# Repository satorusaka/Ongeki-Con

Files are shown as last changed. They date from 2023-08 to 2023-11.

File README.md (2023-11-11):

# ONGEKI Controller Build

DIY Controller for Ongeki.

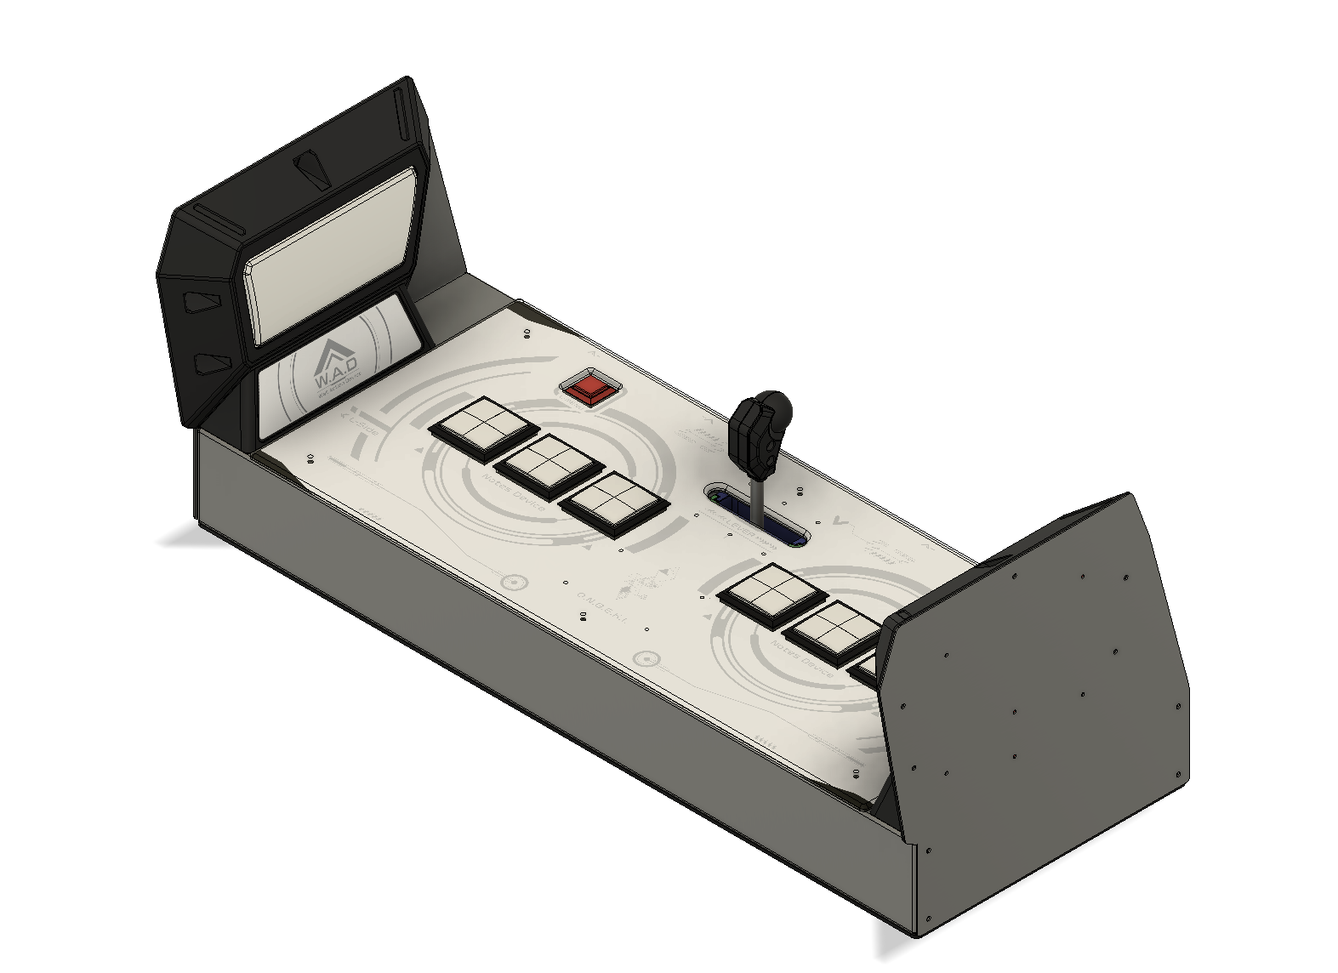
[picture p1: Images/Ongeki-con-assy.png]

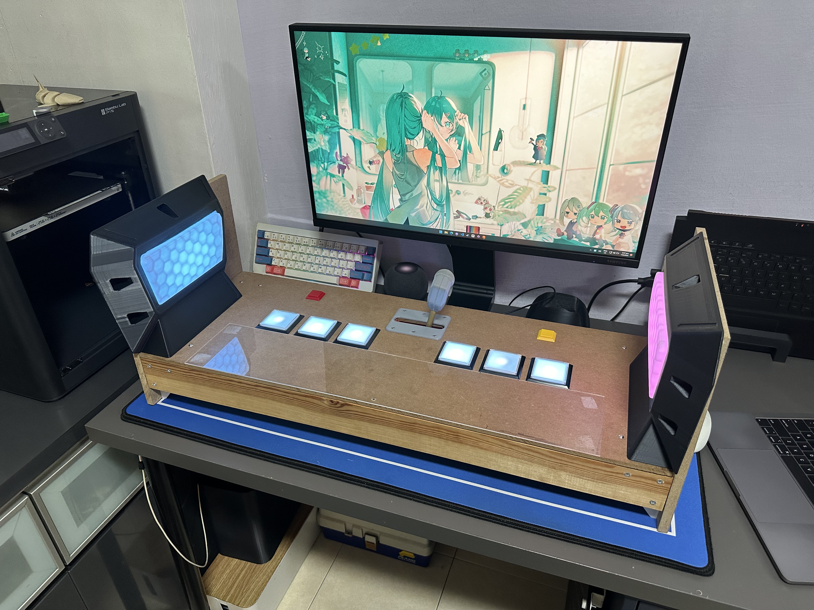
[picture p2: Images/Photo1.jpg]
Assembly photo

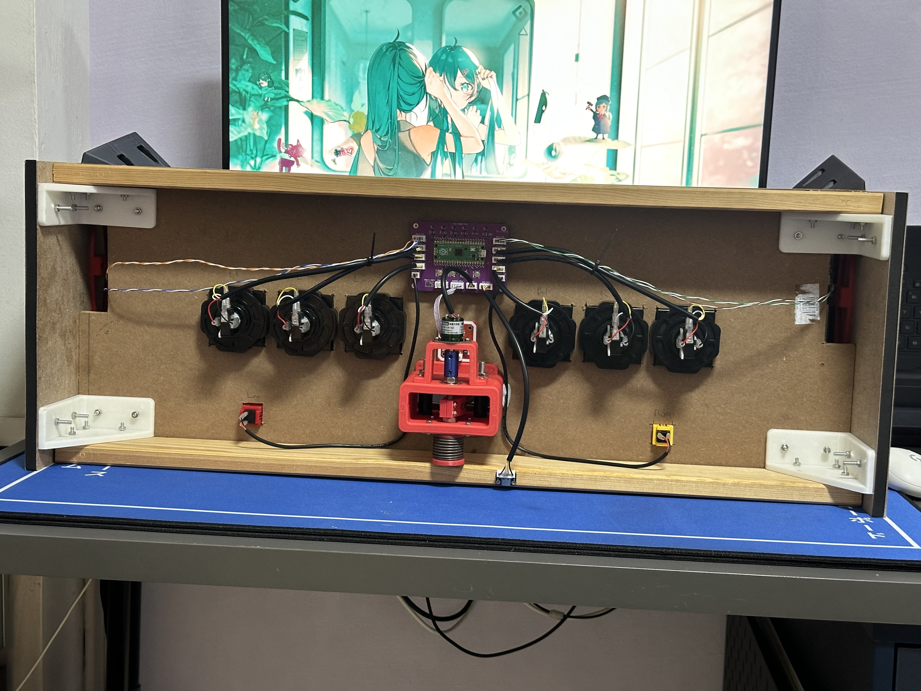
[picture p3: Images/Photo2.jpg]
Assembly photo


## TODO

- Add Main pcb files and documentation
- Complete case design

## Required parts

- 22AWG wire
- various XH connectors
- various Female Spade Crimp Terminals for buttons
- USB-C breakout board

## Raspberry Pi Pico breakout Board (FILES NOT READY)

Documentation in [main-PCB](main-PCB/README.md).
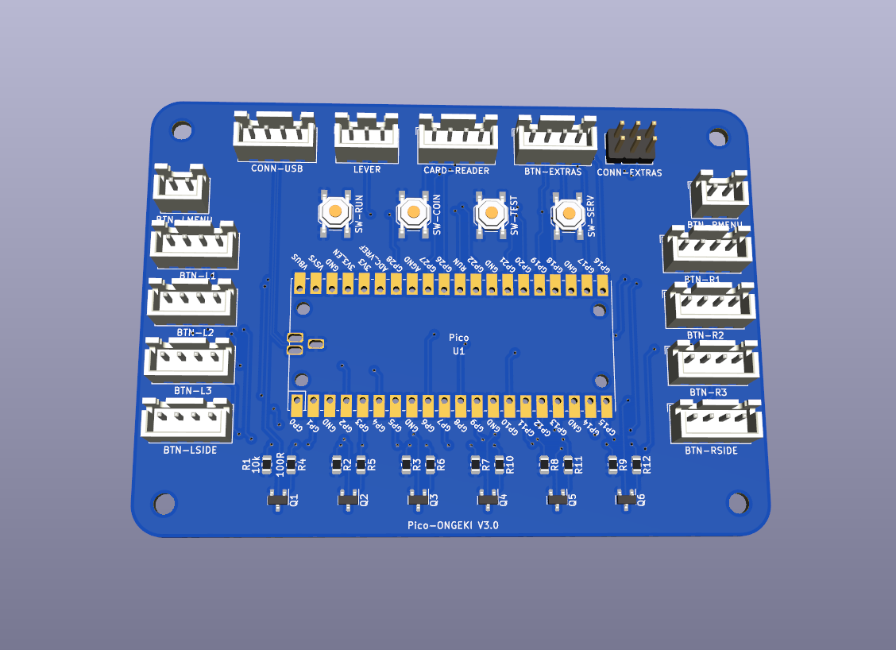
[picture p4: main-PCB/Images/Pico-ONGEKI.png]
Pico-ONFGKI v3.0


## Wall Attack Device (WAD) sub-assembly

Documentation in [WAD assembly](WAD%20assembly/README.md).
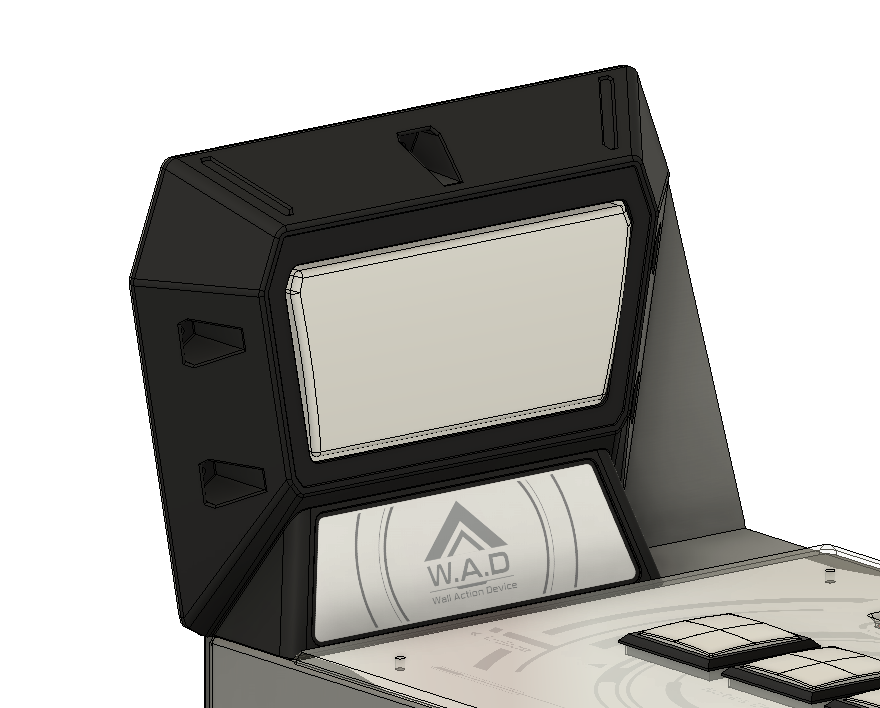
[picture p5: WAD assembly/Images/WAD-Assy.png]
WAD Photo


## Swing Mechanism sub-assembly

Documentation in [Swing assembly](Swing%20assembly/README.md).
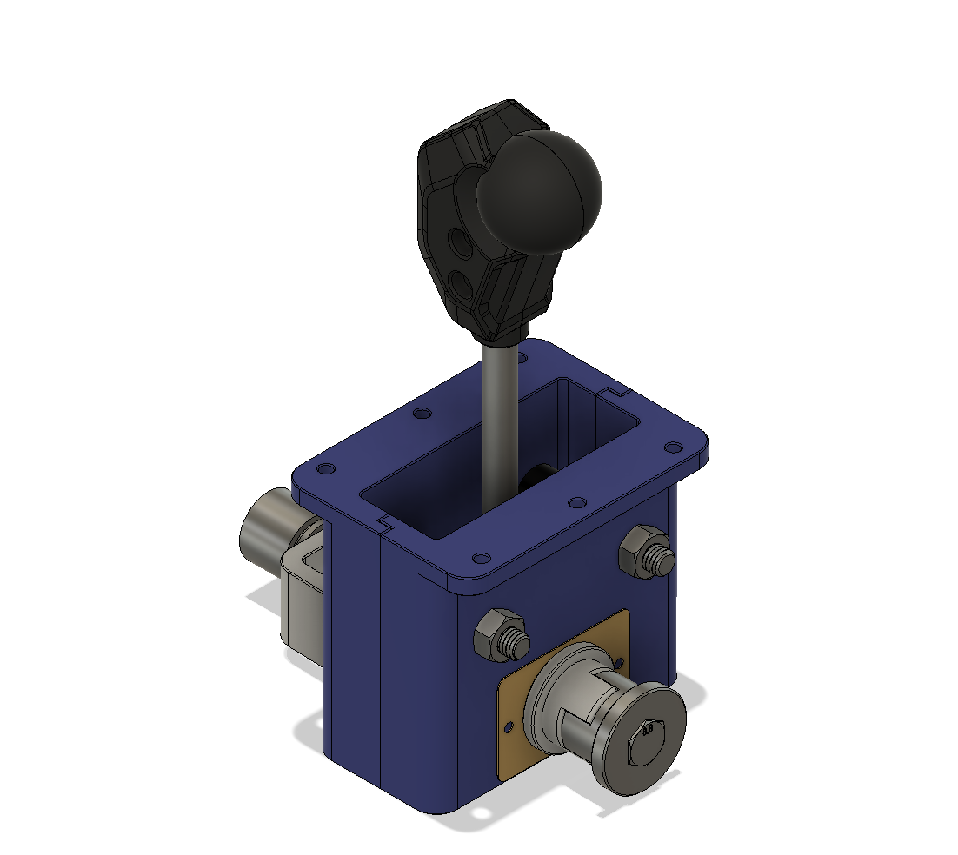
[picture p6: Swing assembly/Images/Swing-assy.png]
Swing Mechanism


## Buttons

[Rhythm-cons.wiki: Buttons Guide](https://rhythm-cons.wiki/w/Buttons)

### Main buttons (x6)

- Sanwa OBSA-60UK 60mm Square button
- using [Mintyleds](https://shop.mon.im/product/mintyleds)
- Links
  - [Sanwa Official Store](https://www.rakuten.co.jp/sanwadenshi/)
  - [IST 60UK](https://www.us.istmall.co.kr/Product/Detail/view/pid/67/cid/)
  - AliExpress: 60mm square arcade button

### Menu buttons (x2) (1 Yellow, 1 Red)

- OBSF-24KK YELLOW & RED 24mm square button
- Links
  - [Sanwa Official Store](https://www.rakuten.co.jp/sanwadenshi/)
  - AliExpress: 24mm square arcade button

### Extra buttons (Test,Service,coin) (x3)

- Sanwa OBSF-24 24mm round buttons
- Links
  - [Sanwa Official Store](https://www.rakuten.co.jp/sanwadenshi/)
  - [IST 24mm](https://www.us.istmall.co.kr/Product/Detail/view/pid/25/cid/)
  - AliExpress: 24mm round arcade button

## Case

- mdf / sheet-metal
- Dimensions: 783x295x90mm (WxDxH)

### WAD Walls

- mdf / sheet-metal
- T-Nut to attach side wall to Main body
- slide down from top to attach

### Control Panel Acrylic

- Dimensions: 669x295mm (WxD)
- 5mm thick
- 3mm chamfers
- 5mm rounded corner

#### Panel Graphics printing options

- [silkscreen printing](https://www.acrylic.com.sg/silkscreen-printing/)
- UV printing
- Poster Paper

# License

This work is licensed under [CC BY-NC-SA 4.0](http://creativecommons.org/licenses/by-nc-sa/4.0/?ref=chooser-v1)

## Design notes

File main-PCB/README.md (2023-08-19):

# Pico-ONGEKI v3.0 (Needs Documenting)

Pico-ONFGKI v3.0

- 13 Buttons connections
  - 6 Main Buttons
    - Button + MintyLED
  - 2 WAD Buttons
    - Button + WS2812b (panel or strips)
  - 2 Menu Buttons
  - Test Button
  - Service Button
  - Coin Button
- Lever analog connector
- USB breakout board connector
- card reader connector

## configuration needed

Needs the correct io file.

Configure COM ports to port 1 & 3. for LED and Card Reader.

update stools conf

```ini
[aime]
enable=0
aimePath=DEVICE\aime.txt

[io4]
enable=0

[io3]
enable=0
```

## Firmware

Thanks \_LittleC\_! [satorusaka/lkick-io4](https://github.com/satorusaka/lkick-io4)

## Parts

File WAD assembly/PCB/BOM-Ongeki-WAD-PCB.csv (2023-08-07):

Comment | Designator | Footprint | LCSC
WS2812B | D1,D2,D3,D4,D5,D6,D7,D8 | LED_WS2812B_PLCC4_5.0x5.0mm_P3.2mm | C2761795
0.1uF | C1,C2,C3,C4,C5,C6,C7,C8 | C_0603_1608Metric | C30926
Conn_01x04 | J2 | JST_XH_S4B-XH-A_1x04_P2.50mm_Horizontal
Conn_01x03 | J1 | JST_XH_S3B-XH-A_1x03_P2.50mm_Horizontal

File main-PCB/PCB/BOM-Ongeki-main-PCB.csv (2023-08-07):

Comment | Designator | Footprint | LCSC
BTN-R1 | J4 | JST_XH_B4B-XH-A_1x04_P2.50mm_Vertical
BTN-R3 | J6 | JST_XH_B4B-XH-A_1x04_P2.50mm_Vertical
Pico | U1 | RPi_Pico_SMD_TH
CARD-READER | J14 | JST_XH_B4B-XH-A_1x04_P2.50mm_Vertical
BTN-L2 | J2 | JST_XH_B4B-XH-A_1x04_P2.50mm_Vertical
BTN-L3 | J3 | JST_XH_B4B-XH-A_1x04_P2.50mm_Vertical
BTN-LMENU | J9 | JST_XH_B2B-XH-A_1x02_P2.50mm_Vertical
BTN-LSIDE | J7 | JST_XH_B4B-XH-A_1x04_P2.50mm_Vertical
BTN-RSIDE | J8 | JST_XH_B4B-XH-A_1x04_P2.50mm_Vertical
BTN-RMENU | J10 | JST_XH_B2B-XH-A_1x02_P2.50mm_Vertical
BTN-L1 | J1 | JST_XH_B4B-XH-A_1x04_P2.50mm_Vertical
LEVER | J15 | JST_XH_B3B-XH-A_1x03_P2.50mm_Vertical
BTN-R2 | J5 | JST_XH_B4B-XH-A_1x04_P2.50mm_Vertical
BTN-EXTRAS | J18 | JST_XH_B4B-XH-A_1x04_P2.50mm_Vertical
CONN-EXTRAS | J17 | PinHeader_2x03_P2.54mm_Vertical
SW-RUN | SW1 | SW_SPST_TL3342
CONN-USB | J16 | JST_XH_B4B-XH-A_1x04_P2.50mm_Vertical
10k | R2 | R_0805_2012Metric
100R | R4 | R_0805_2012Metric
SW-SERV | SW2 | SW_SPST_TL3342
BSS138 | Q6 | SOT-23
100R | R6 | R_0805_2012Metric
10k | R3 | R_0805_2012Metric
10k | R9 | R_0805_2012Metric
BSS138 | Q2 | SOT-23
BSS138 | Q1 | SOT-23
10k | R8 | R_0805_2012Metric
100R | R10 | R_0805_2012Metric
10k | R1 | R_0805_2012Metric
10k | R7 | R_0805_2012Metric
SW-TEST | SW3 | SW_SPST_TL3342
BSS138 | Q5 | SOT-23
100R | R5 | R_0805_2012Metric
BSS138 | Q3 | SOT-23
BSS138 | Q4 | SOT-23
SW-COIN | SW4 | SW_SPST_TL3342
100R | R11 | R_0805_2012Metric
100R | R12 | R_0805_2012Metric

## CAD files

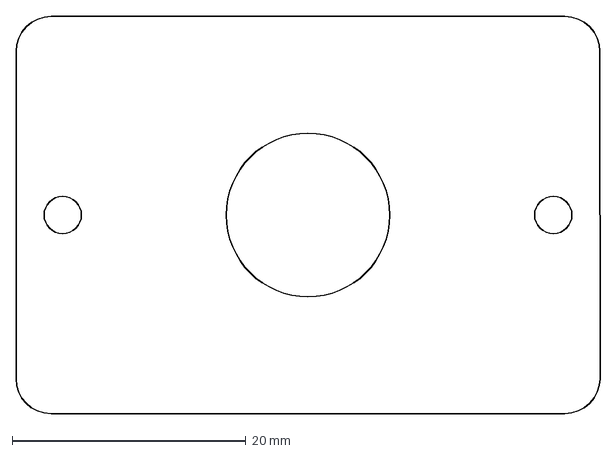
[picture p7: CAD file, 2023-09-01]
Swing assembly/DXF/Friction Plate.dxf
50.0 x 34.0 mm

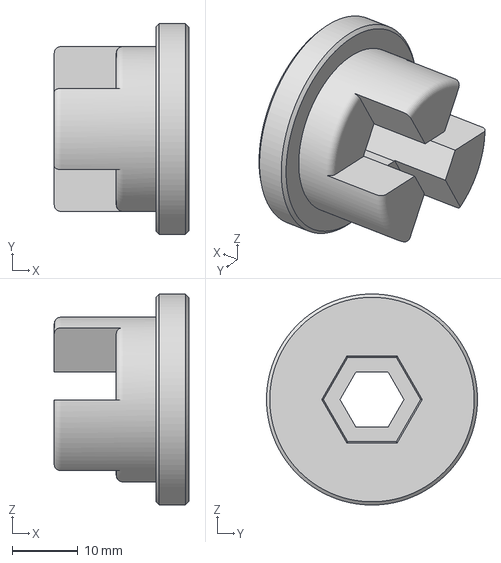
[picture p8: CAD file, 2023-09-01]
Swing assembly/STLs/Spring Holder B.3mf
20.4 x 32.0 x 32.0 mm

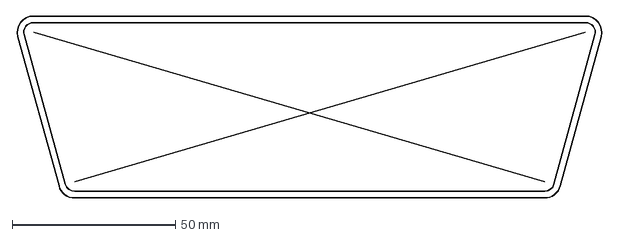
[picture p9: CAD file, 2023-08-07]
WAD assembly/Decal/WAD Decal Size.dxf
179.7 x 55.8 mm

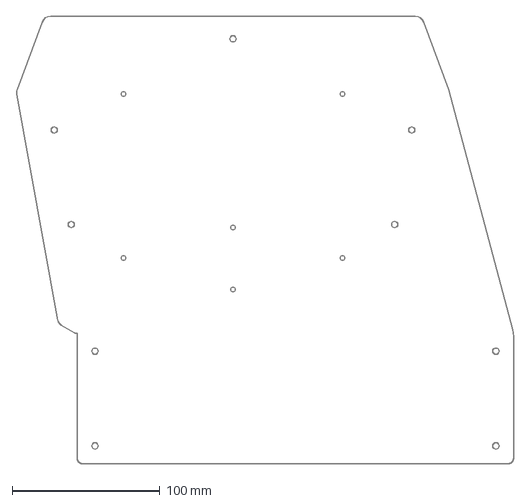
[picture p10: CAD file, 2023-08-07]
WAD assembly/DXFs/Side-Panel.dxf
336.1 x 302.4 mm

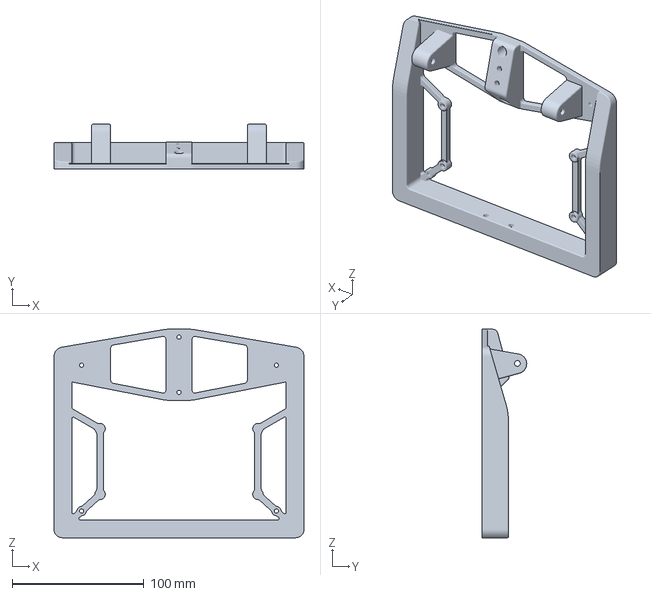
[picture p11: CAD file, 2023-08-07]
WAD assembly/STLs/WAD - Button Frame.3mf
190.0 x 33.9 x 158.5 mm

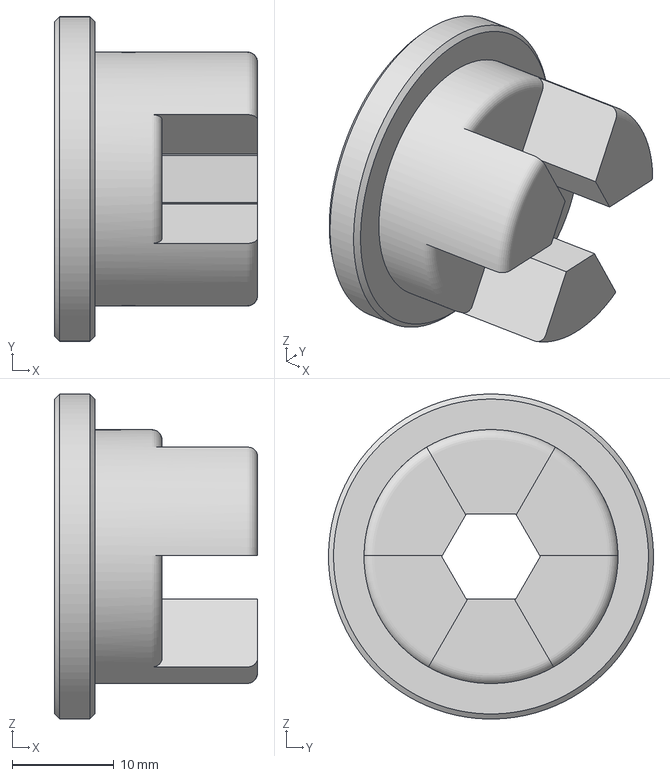
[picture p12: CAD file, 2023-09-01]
Swing assembly/STLs/Spring Holder A.3mf
20.0 x 32.0 x 32.0 mm

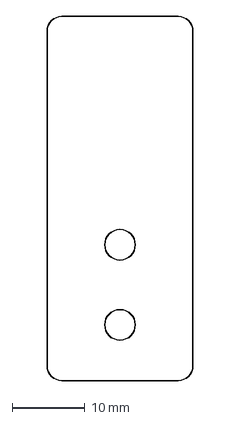
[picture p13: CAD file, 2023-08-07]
WAD assembly/DXFs/Flat Spring.dxf
20.0 x 50.0 mm

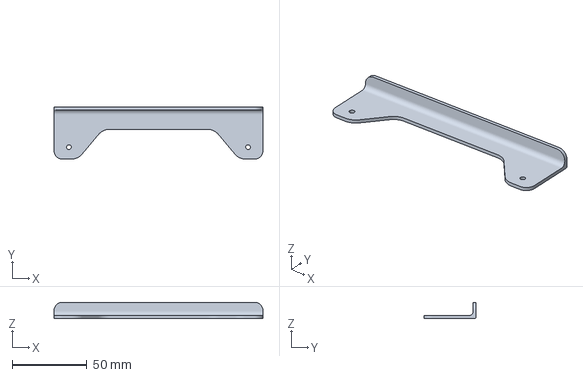
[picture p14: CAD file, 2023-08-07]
WAD assembly/STLs/WAD - Button Limiter.3mf
140.0 x 35.0 x 11.0 mm

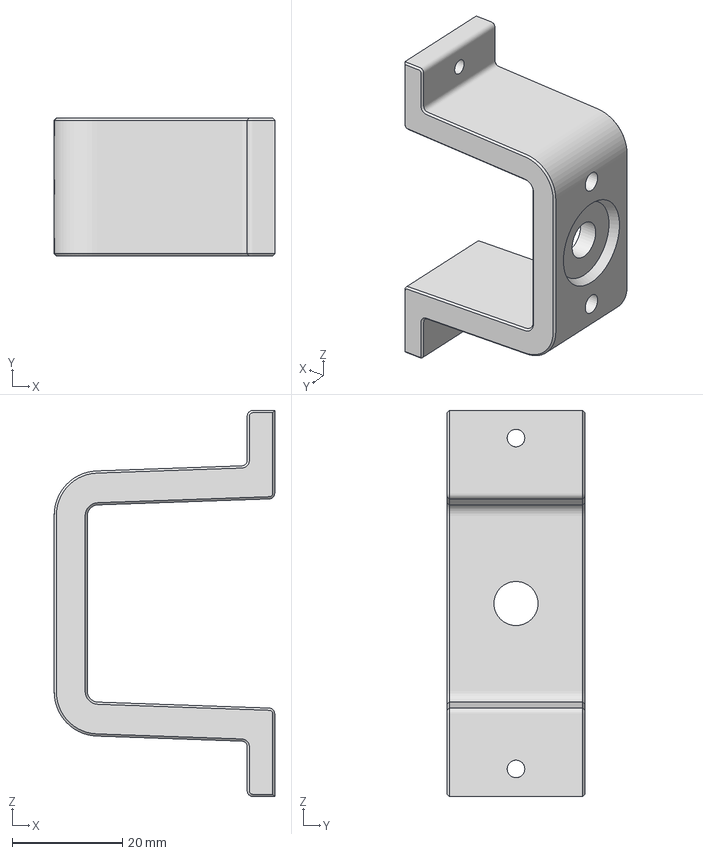
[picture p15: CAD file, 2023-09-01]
Swing assembly/STLs/Sensor Holder.3mf
40.0 x 25.0 x 70.0 mm

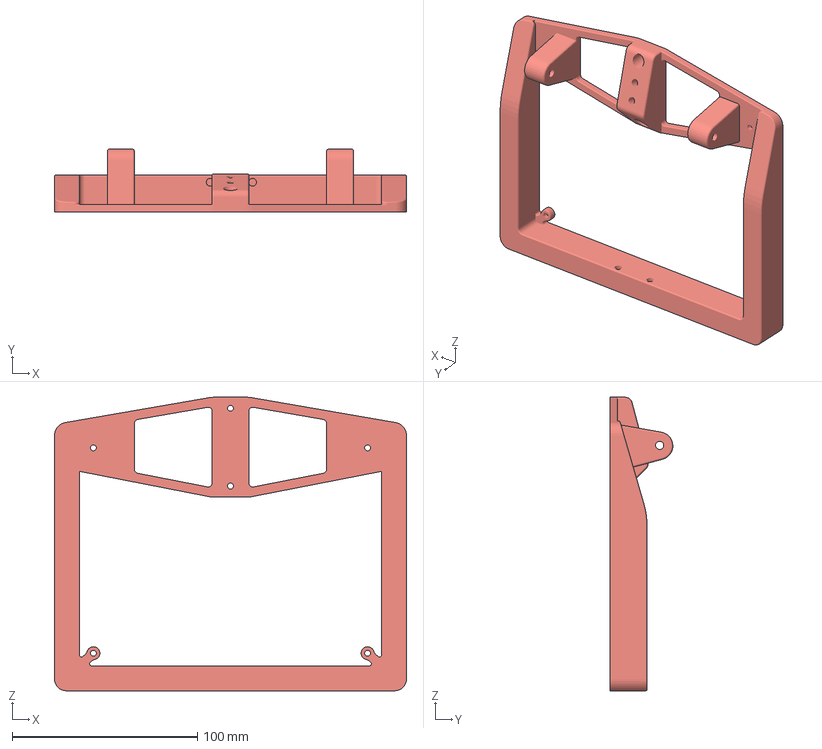
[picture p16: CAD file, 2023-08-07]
WAD assembly/STLs/WAD - Button Frame (No PCB).3mf
190.0 x 33.9 x 158.5 mm

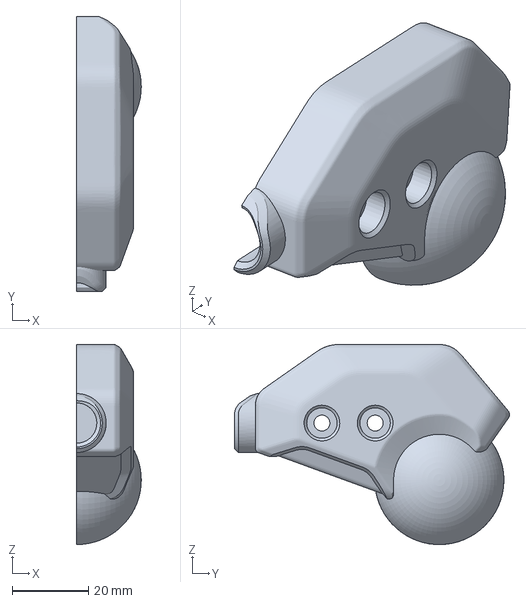
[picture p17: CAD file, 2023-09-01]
Swing assembly/STLs/Knob_R.3mf
17.0 x 72.3 x 52.7 mm

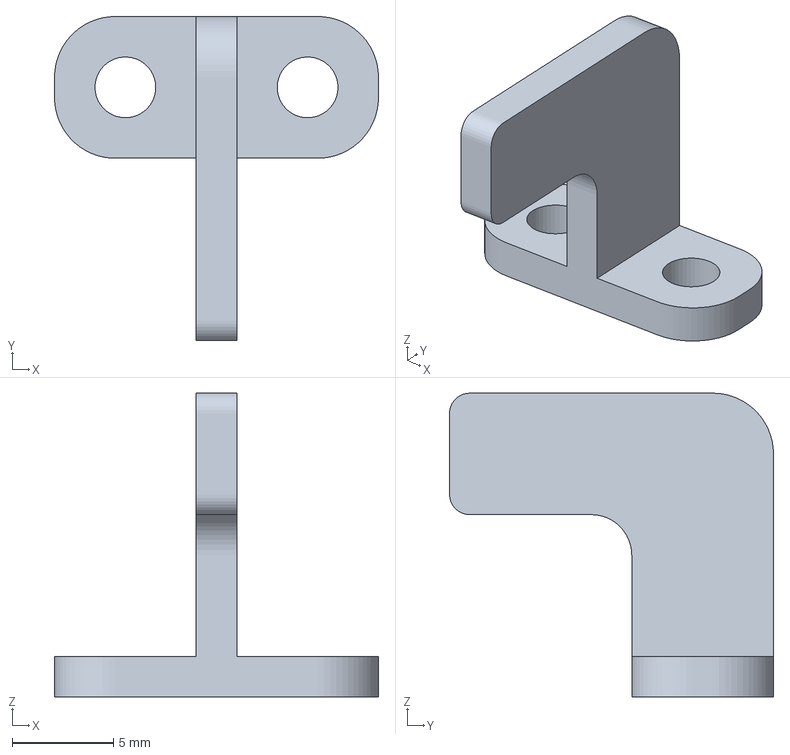
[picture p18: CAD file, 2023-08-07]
WAD assembly/STLs/WAD - Sensor Trigger.3mf
16.0 x 16.0 x 15.0 mm

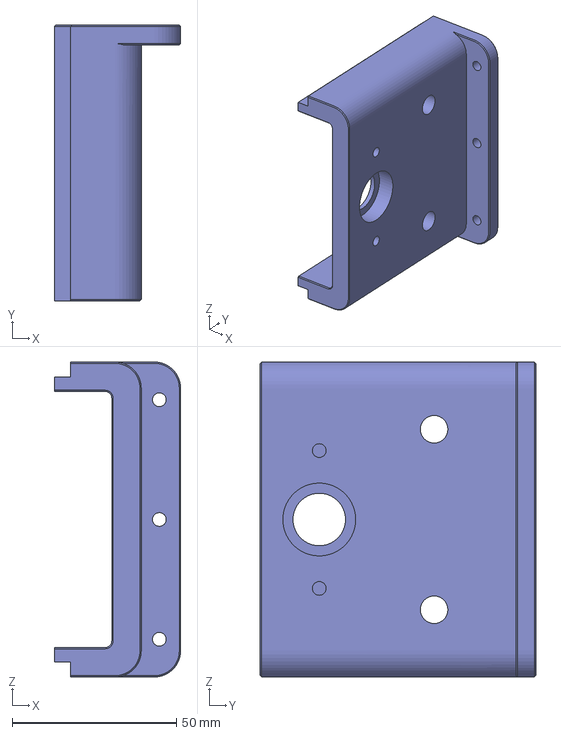
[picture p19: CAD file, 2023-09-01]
Swing assembly/STLs/Mount A.3mf
38.5 x 84.0 x 96.0 mm

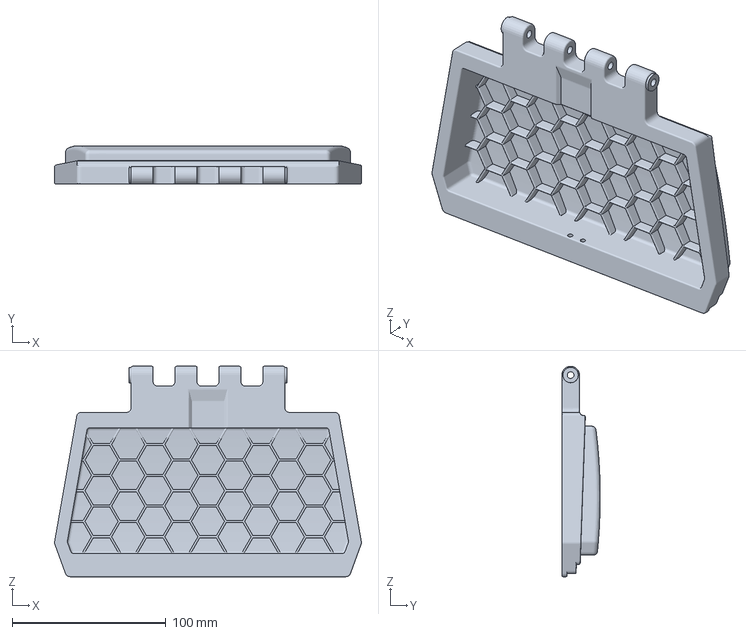
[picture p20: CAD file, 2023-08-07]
WAD assembly/STLs/WAD - Button Face.3mf
199.8 x 25.0 x 137.0 mm

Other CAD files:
Swing assembly/STLs/Mount B.3mf
WAD assembly/STLs/WAD - Cover.3mf
Swing assembly/STLs/Knob_L.3mf
Swing assembly/STLs/T-Coupler.3mf

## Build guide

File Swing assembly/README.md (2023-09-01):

# Swing Mechanism sub-assembly

I've designed this to be accurate to the original design and function.

There is a STEP file provided for this assembly, you can use it as a guide or modify it to your needs.

assy
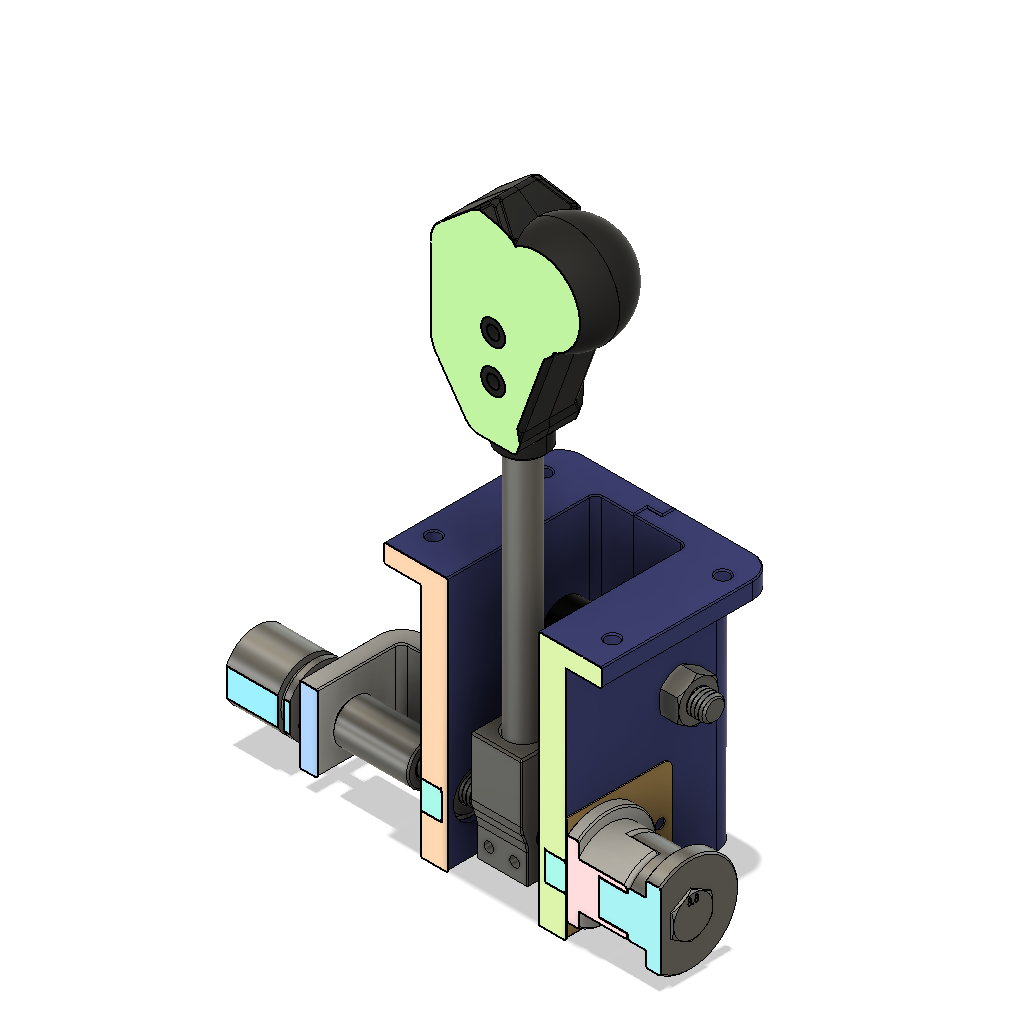
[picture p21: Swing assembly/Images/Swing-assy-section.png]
assy


[Photos below](#gallery)

## Required Parts

Additional custom parts and printed parts below.

| Part | Qty | Links |
| --- | --- | --- |
| Rubber Tube (8mm ID, 15mm OD, 23mm Length) | 2 | [8x14mm \(Cheaper\)](https://www.aliexpress.com/item/1005001683018083.html) or [8x15mm](https://www.aliexpress.com/item/1005001474127393.html) |
| Compression Spring (Wire Dia. : 2mm, Len. : 80mm, OD: 30mm) | 1 | [AliExpress](https://www.aliexpress.com/item/4000436939383.html) |
| Angle sensor 0-3.3V output | 1 | [AliExpress](https://www.aliexpress.com/item/32422949989.html) |
| 6x8 Shaft Coupler (D:14, L:25) | 1 | [AliExpress](https://www.aliexpress.com/item/1005001891597730.html) |
| 608 bearing | 2 | |
| M8x90 Hex Bolt. **pivot rod.** | 1 | |
| M8x60 Hex Bolt. **Stopper Rods.** | 2 | |
| M8 nuts (use threadlocker on pivot rod) | 5 | |
| M3x6 Bolt **angle sensor** | 2 | |
| M3 Countersunk Bolts(x6). (Len: 6mm + thickness of casing.) | 6 | |
| M3x10 Bolts **Friction plate** | 2 | |
| M3x16 Bolts **T-Coupler clamp** | 2 | |
| M3x6 Bolts **T-Coupler Handle rod** | 2 | |
| M3 Treaded Inserts | 12  | |
| M3 nuts | 2 | |
| Grease | 1 | |

## Printed Parts

| Parts | Qty | Notes |
| --- | --- | --- |
| Knob | 1 | |
| Mounts A & B | 1 | |
| sensor holder | 1 | |
| spring holder A & B | 1 | Recommended to print in PETG |
| T-coupler | 1 | Recommended to print in PETG |

## Custom Parts

### Handle Rod

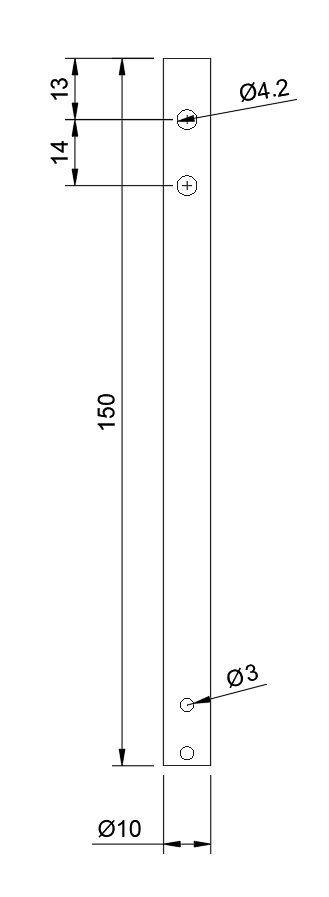
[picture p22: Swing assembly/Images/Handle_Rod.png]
Handle Rod Dimensions


- 10mm Dia., 150mm Len.
- brass/steel

### Friction Plate

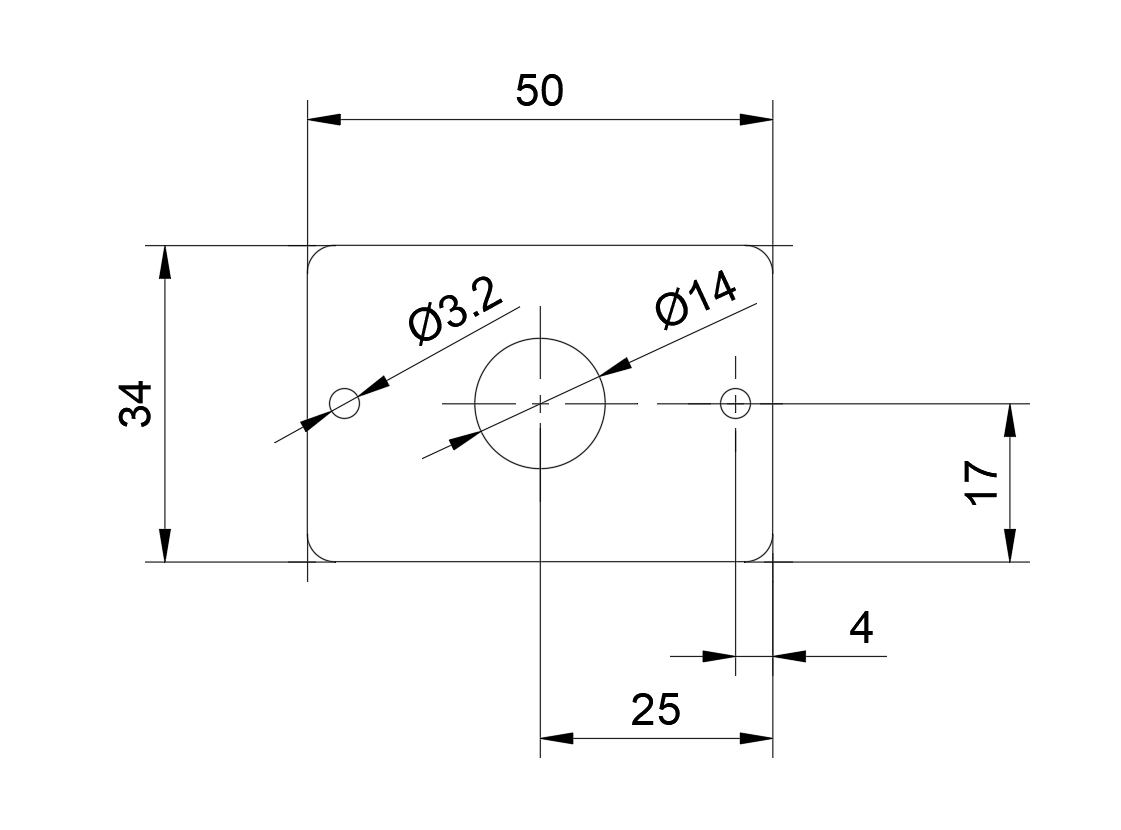
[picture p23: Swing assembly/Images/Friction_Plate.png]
Friction Plate Dimensions


- Dimensions: 34x50mm
- thickness: 0.64mm
- Sheet brass/steel
- apply grease on contacting surface.

## Gallery

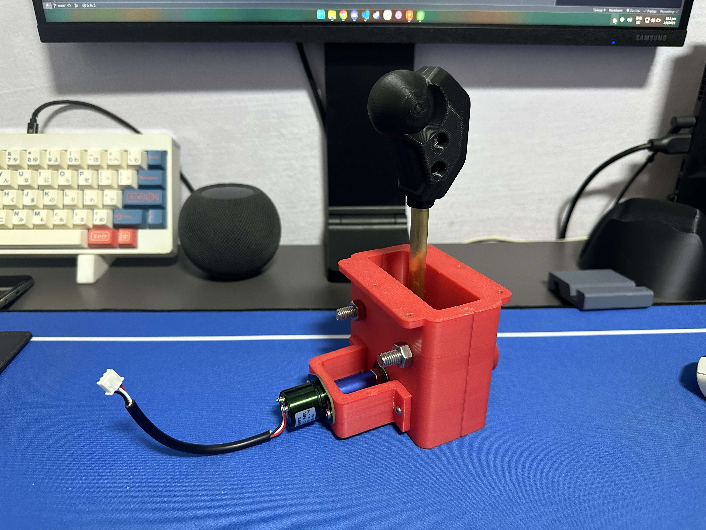
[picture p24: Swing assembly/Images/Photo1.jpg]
SwingAssy Photo

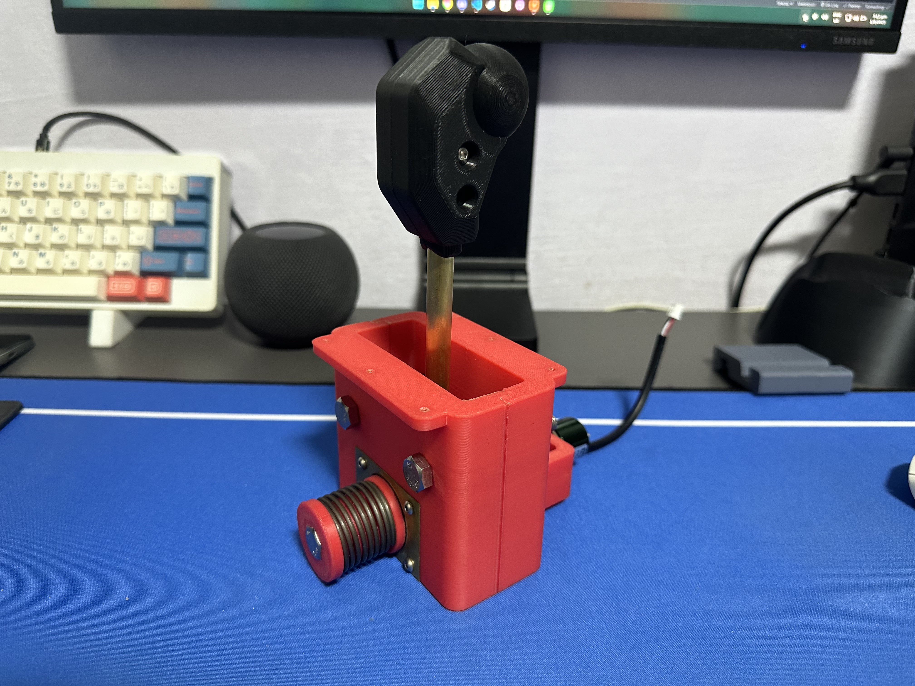
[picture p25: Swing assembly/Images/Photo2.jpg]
SwingAssy Photo

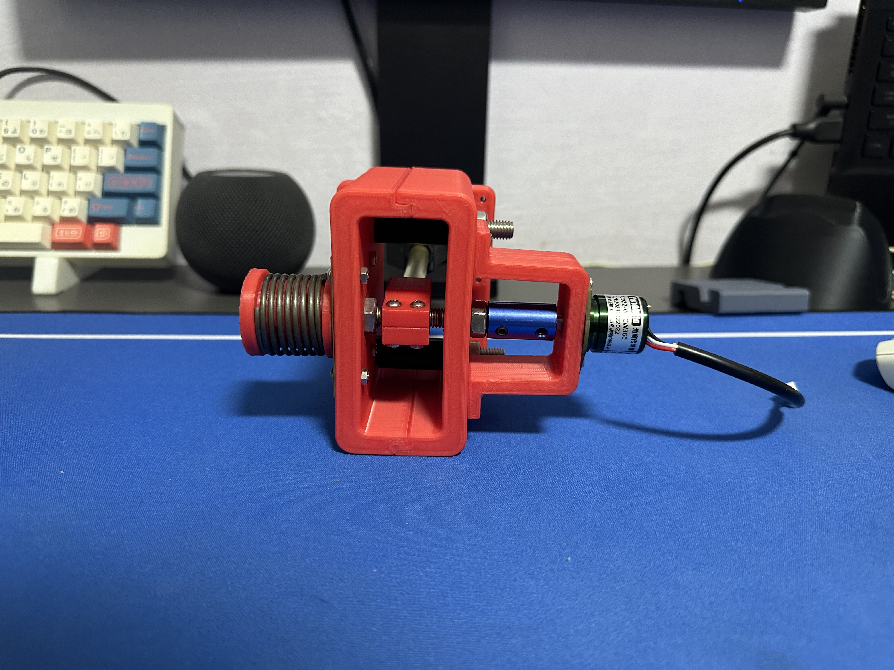
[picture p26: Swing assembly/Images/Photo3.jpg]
SwingAssy Photo


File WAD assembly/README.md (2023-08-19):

# Wall Attack Device (WAD) sub-assembly

I've designed this WAD to be accurate to the original design and function, using photo sensor for trigger, and flat spring for return mechanism.

There is a STEP file provided for this assembly, you can use it as a guide or modify it to your needs.

WAD Photo

[Photos below](#gallery)

## Required Parts

parts needed for the PCB are listed under the [PCB Section](#custom-wad-pcb). Additional custom parts and printed parts below.

| Part | Qty | Links |
| --- | --- | --- |
| LG-JT01 photo interrupter | 2 | [AliExpress](https://www.aliexpress.com/item/33015487463.html) |
| JST H3P-SHF-AA\* | 1 | [LCSC](https://www.lcsc.com/product-detail/_JST-Sales-America-_C495211.html) |
| JST SHF-001T-0.8BS\* | 3 | [LCSC](https://www.lcsc.com/product-detail/_JST-Sales-America-_C141769.html) |
| EVA foam tape, single sided, 10mm width, 1mm thick | 1 roll | [AliExpress](https://www.aliexpress.com/item/1005001829983926.html) |
| m3 threaded inserts | (x9 with pcb) or (x5 no pcb) | |
| m3x4 bolts | 4 (x2 for flat spring) (x2 for sensor trigger) | |
| m3x6 bolts | 6 (x4 for PCB) (x2 for Button Limiter) | |
| m3 bolts (button frame to side panel)\*\* | 6 | |
| m4 bolts (WAD cover to side panel)\*\* | 5 | |
| m3 and m4 nuts | | |

\* for connecting LG-JT01, alternatively you can use dupont connectors.

\*\* bolt length depends on panel thickness

## Printed Parts

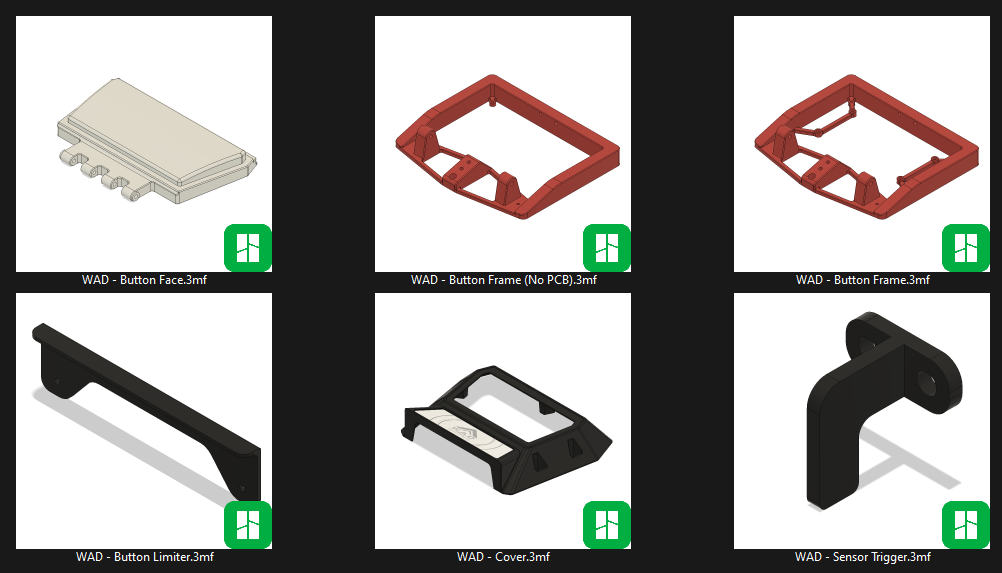
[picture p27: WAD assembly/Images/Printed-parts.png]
Printed Parts


Print 2 each, 1 per side. I recommend printing the button face vertically for a nicer looking surface.

| Parts | Qty | Notes |
| --- | --- | --- |
| Button Face | 2 | |
| Sensor Trigger | 2 | |
| Button Limiter | 2 | |
| WAD Cover | 2 | |
| Button Frame | 2 | Use (No PCB) if you are use LED strips instead of Custom WAD PCB |

## Custom Parts

### Flat Spring

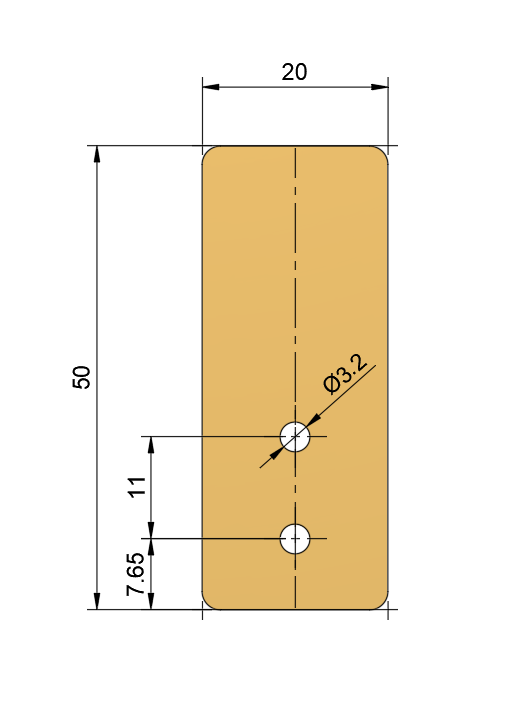
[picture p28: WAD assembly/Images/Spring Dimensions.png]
Flat Spring Dimensions


- Dimensions: 20x50mm
- thickness: 0.64mm
- Sheet brass/steel
- apply grease on contacting surface.

### Pivot Shaft

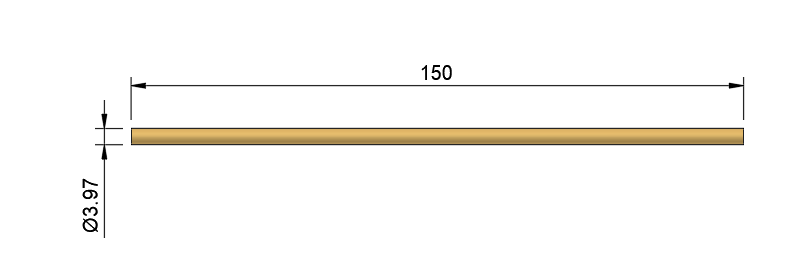
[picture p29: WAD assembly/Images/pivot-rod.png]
Pivot Dimensions


- 3.97mm dia., 150mm length
  Optionally, you can tap rod ends with M4 threads and use m4 nuts and washers on both ends to secure. personally I just use friction fit

### Custom WAD PCB

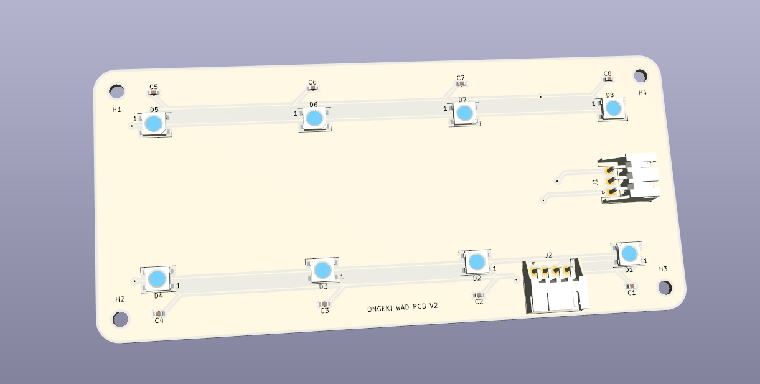
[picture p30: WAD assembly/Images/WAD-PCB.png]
WAD PCB


LED Panel with cable passthrough for Photosensor. Alternatively, you can use WS2812b LED Strips in place of the PCB.

#### BOM

| Part | qty |
| --- | --- |
| WS2812B | 8 |
| 0.1uF 0603 Capacitor | 8 |
| JST S4B-XH-A-1 | 1 |
| JST S3B-XH-A-1 | 1 |
| JST XHP-4 | 1 |
| JST XHP-3 | 1 |
| JST XH contacts | 7 |

### Sticker Decal
dimensions to be added. 
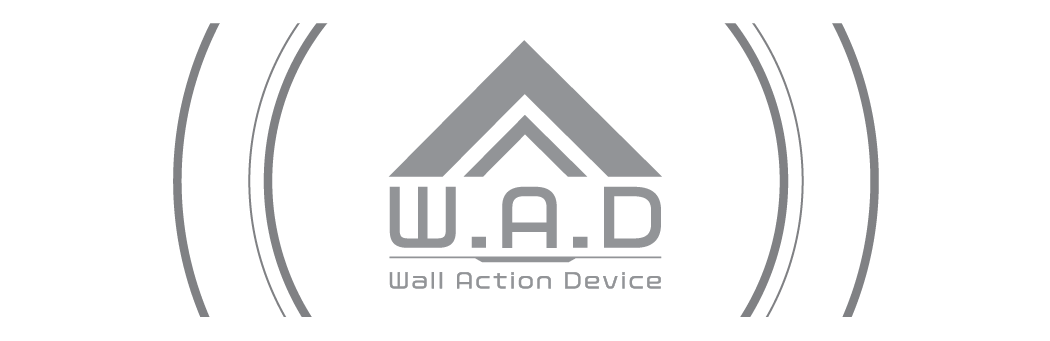
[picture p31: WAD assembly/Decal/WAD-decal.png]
wad decal


## Gallery

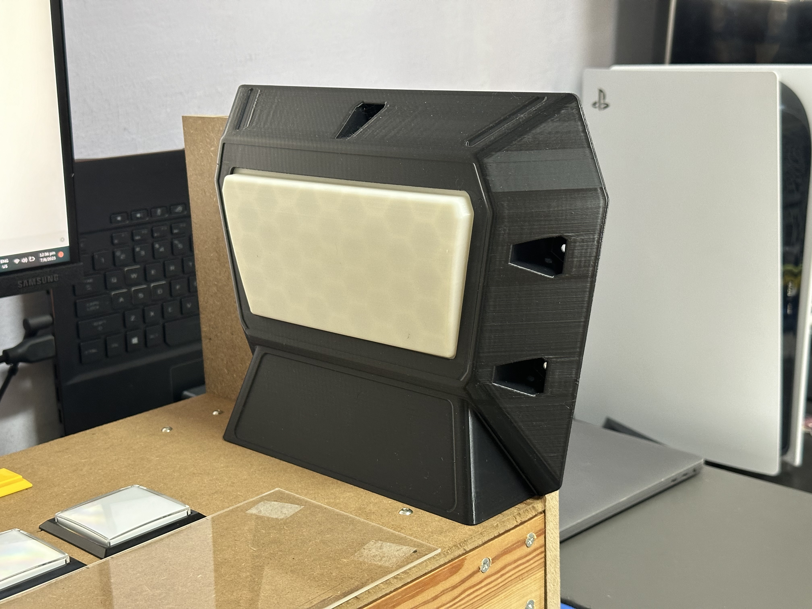
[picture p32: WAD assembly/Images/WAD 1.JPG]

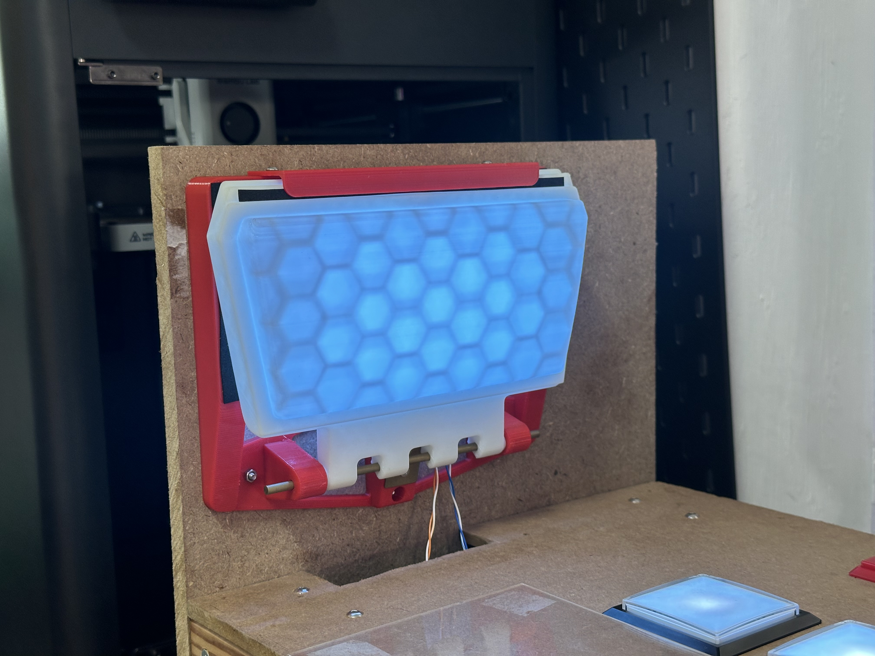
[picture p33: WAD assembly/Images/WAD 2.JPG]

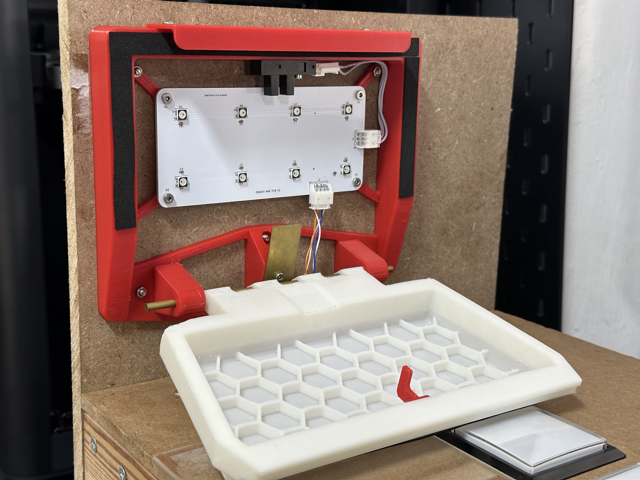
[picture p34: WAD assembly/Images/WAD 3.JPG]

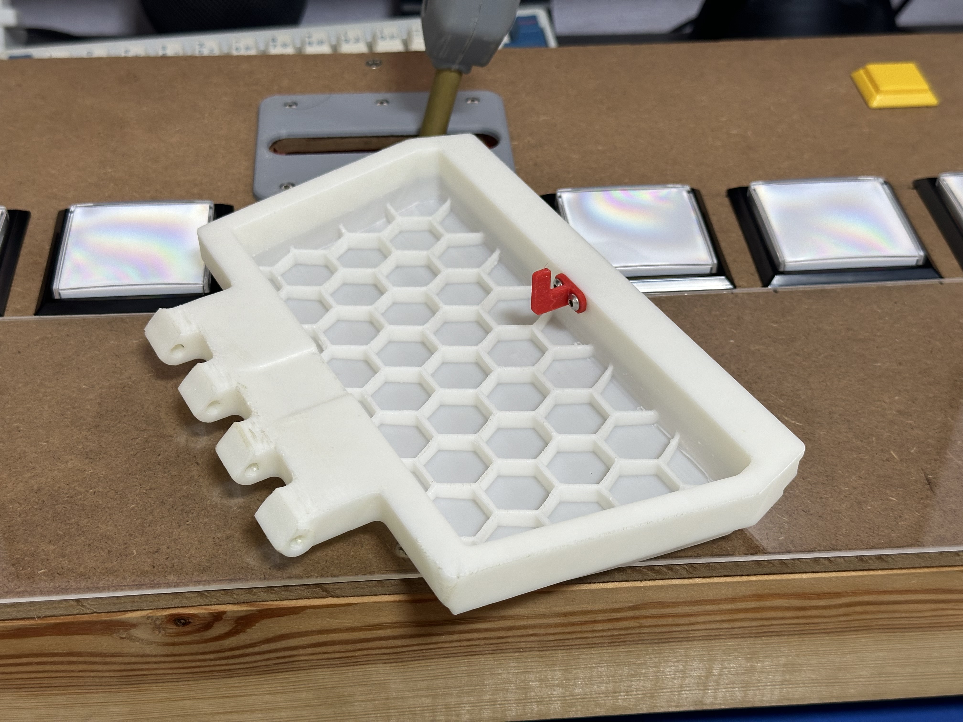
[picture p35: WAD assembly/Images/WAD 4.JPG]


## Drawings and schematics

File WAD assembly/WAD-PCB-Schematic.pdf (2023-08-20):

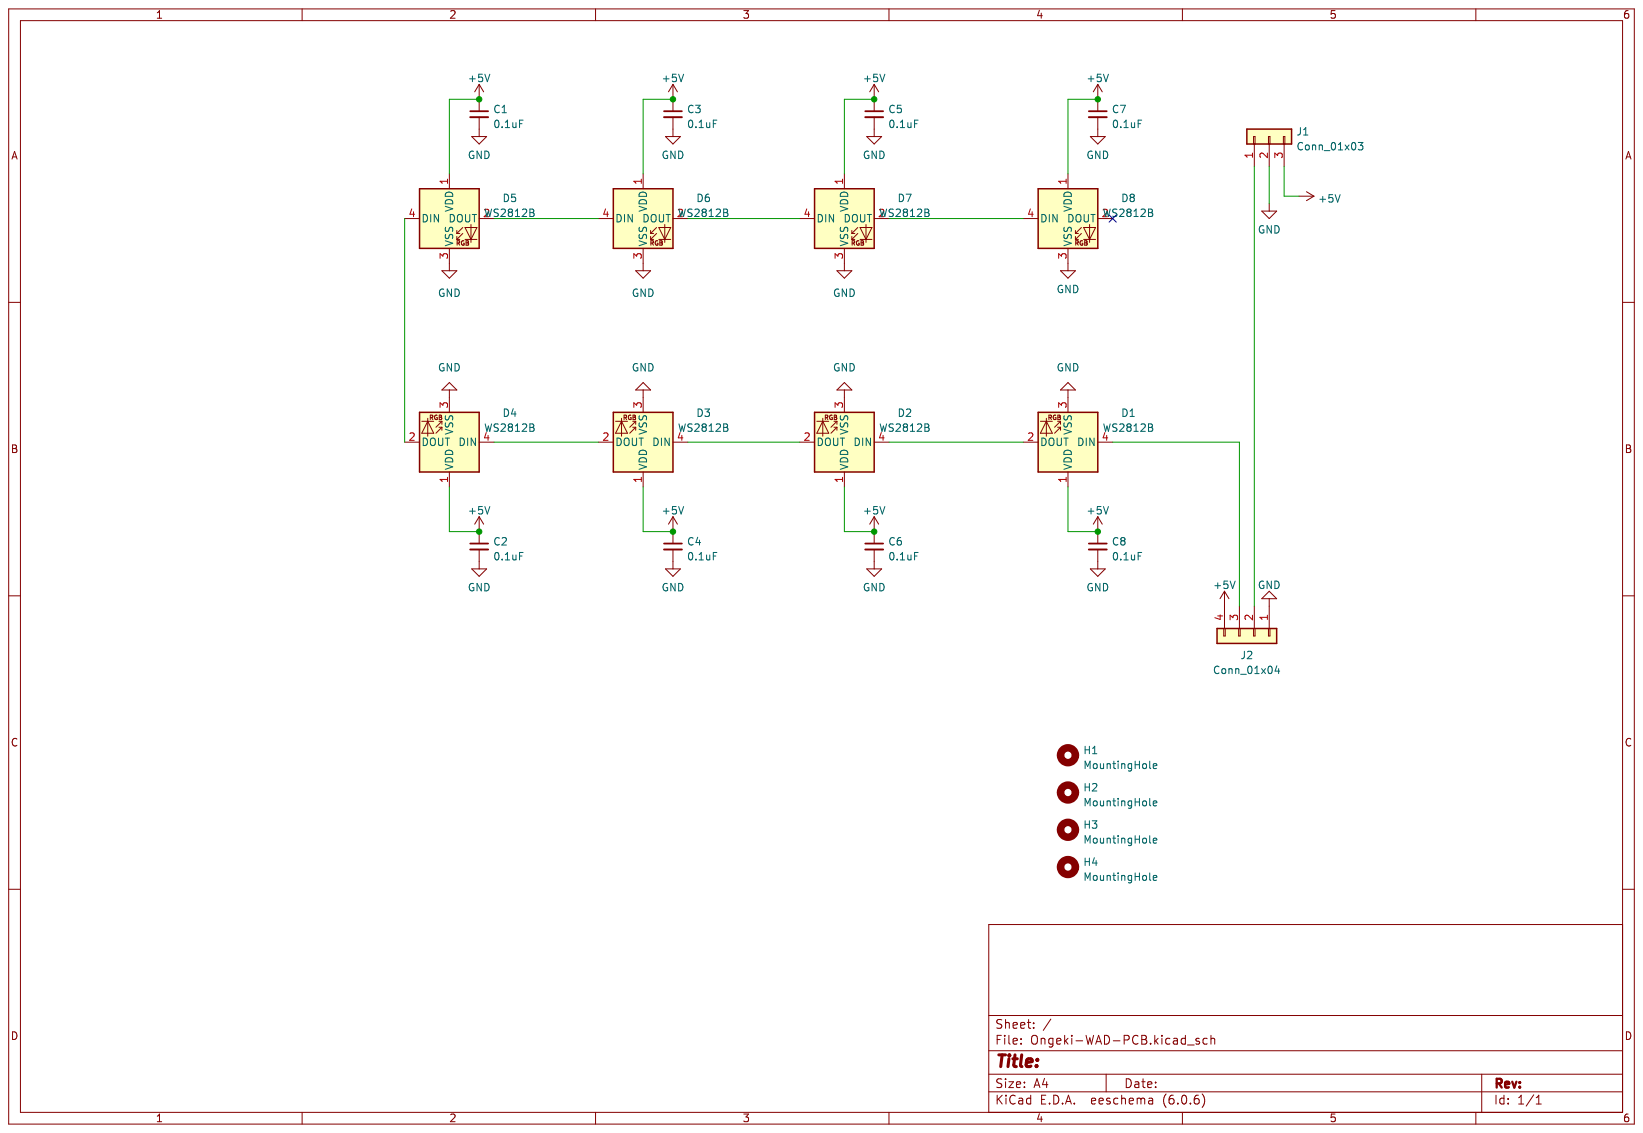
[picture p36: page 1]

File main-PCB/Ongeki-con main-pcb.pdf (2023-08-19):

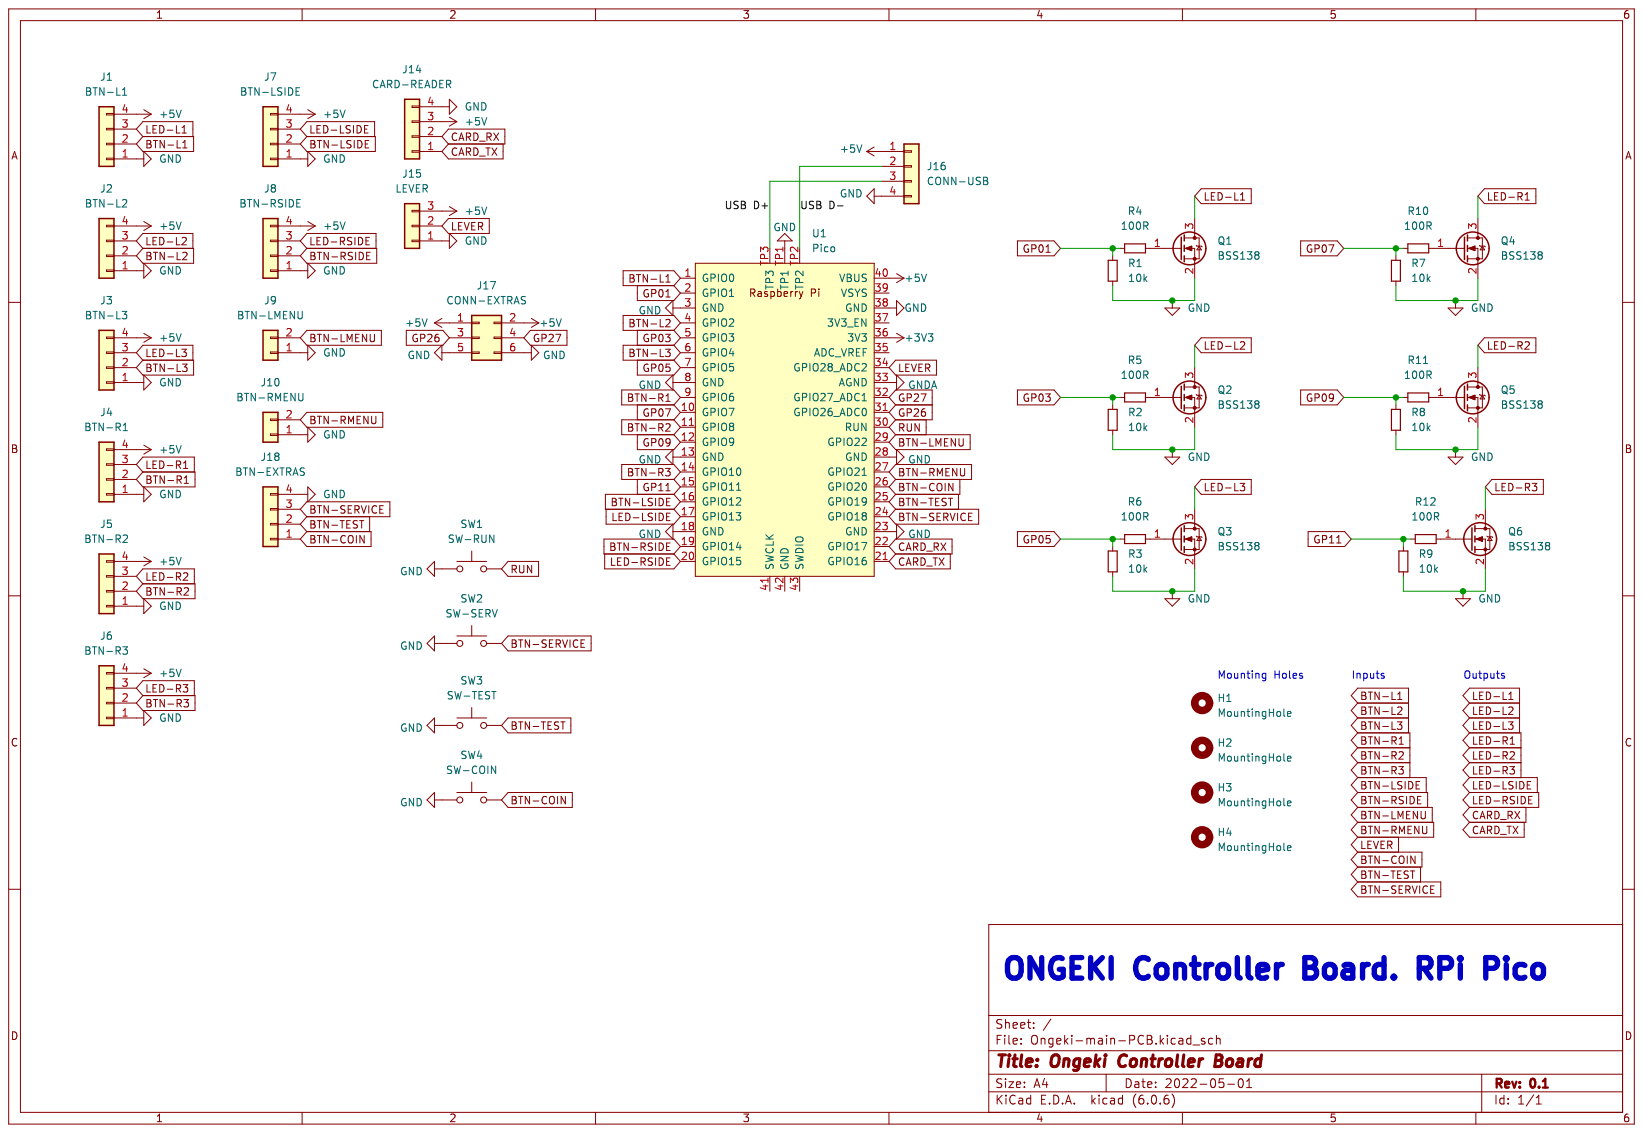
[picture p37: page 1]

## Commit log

2023-08-07 update docs
    [Flat Spring.dxf]
2023-08-07 updated wad documenting
    [Side-Panel.dxf, WAD Decal Size.dxf]
2023-08-07 added images
    [BOM-Ongeki-main-PCB.csv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]
2023-08-19 Create Ongeki-con main-pcb.pdf
2023-09-01 added Lever files
    [Friction Plate.dxf, Knob_L.3mf, Knob_R.3mf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]
